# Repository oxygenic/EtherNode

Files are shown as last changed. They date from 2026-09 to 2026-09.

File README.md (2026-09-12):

# EtherNode
Slim STM32H7-based Ethernet device with several IOs and signal types which can be controlled via Telnet, supports MODBUS, REST and MQTT as well as small programs running from the device directly 

The EtherNode is an industrial IO-extender that comes with different types of input- and output-signals and a wide range of communication interfaces. Thus it can be used as remote Ethernet IO-module for different other scenarios and applications. Possible usage scenarios would be applications where the EtherNode acts as slim TCP module for a PLC and where it autonomously performs distributed and remote I/O operations that are triggered via simple and easy to use commands.

The EtherNode Compact IO module can be integrated into every machine network and provides the following features:
- wide-range power supply allows input voltages from 9V to 32V
- 8 galvanically insulated digital inputs which can be operated with external power in range 5..24V
- 2 of the digital inputs optionally can be used with a quadrature encoder for counting steps (position), speed and acceleration
- 8 galvanically insulated digital outputs which can be operated with external power in range 5..24V
- 2 of the digital outputs optionally can issue freely definable frequencies of up to 500 kHz with programmable pulse-width (PWM)
- 2 of the digital outputs optionally can be used to drive control two stepper motor axes with a step frequency of up to 100 kHz, acceleration ramps and referencing
- 2 high-impedance analogue inputs in range 0..10V with a resolution of 16 bits
- Ethernet interface to connect with host (control-PC / embedded device / PLC)
- control via Telnet ASCII commands, MODBUS, MQTT (plain and JSON) or HTTP REST API (plain and JSON)
- stand-alone operation: conditions and flows can be defined and stored on the device for autonomous operation wiht and without communication via the communication interfaces
- fully operational with any control device such as a PLC or even a plain PC or a Raspberry Pi
- board designed to fit into compact housing with DIN rail mounting clamp available at https://de.rs-online.com/web/p/din-schienen-gehause/1862290 and at https://de.rs-online.com/web/p/din-schienen-gehause/0336868

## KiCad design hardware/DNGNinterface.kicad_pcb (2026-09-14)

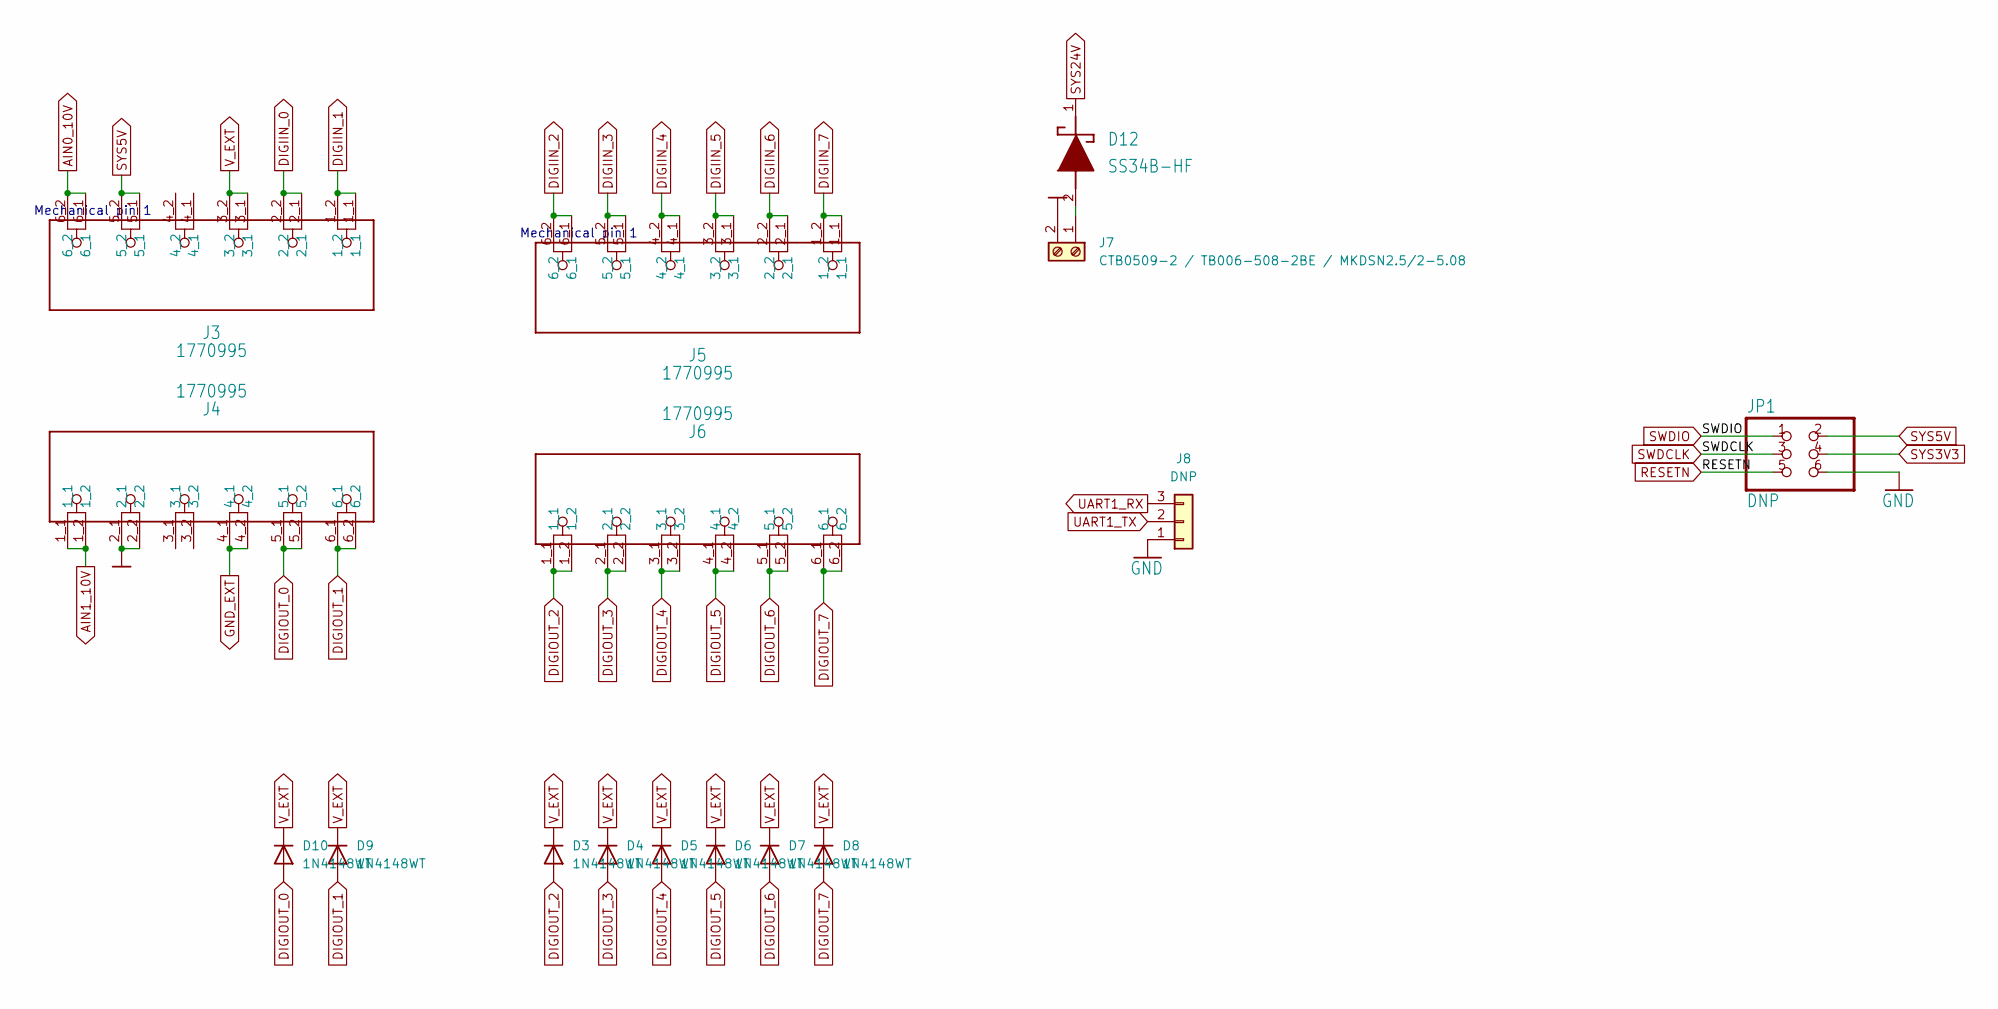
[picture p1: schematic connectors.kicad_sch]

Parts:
D3, D4, D5, D6, D7, D8, D9, D10: 1N4148WT; D_SOD-523
D12: SS34B-HF; SS34
J3, J4, J5, J6: 1770995; PHOENIX_1770995
J7: CTB0509-2 / TB006-508-2BE / MKDSN2.5/2-5.08; TerminalBlock_Phoenix_MKDS-1,5-2-5.08_1x02_P5.08mm_Horizont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
J8: DNP; PinHeader_1x03_P2.54mm_Vertical
JP1: DNP; PinHeader_2x03_P2.54mm_Vertical

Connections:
AIN0_10V: J3.6_1, J3.6_2; also elsewhere on the board
AIN1_10V: J4.1_1, J4.1_2; also elsewhere on the board
DIGIIN_0: J3.2_1, J3.2_2; also elsewhere on the board
DIGIIN_1: J3.1_1, J3.1_2; also elsewhere on the board
DIGIIN_2: J5.6_1, J5.6_2; also elsewhere on the board
DIGIIN_3: J5.5_1, J5.5_2; also elsewhere on the board
DIGIIN_4: J5.4_1, J5.4_2; also elsewhere on the board
DIGIIN_5: J5.3_1, J5.3_2; also elsewhere on the board
DIGIIN_6: J5.2_1, J5.2_2; also elsewhere on the board
DIGIIN_7: J5.1_1, J5.1_2; also elsewhere on the board
DIGIOUT_0: D10.2 (A), J4.5_1, J4.5_2; also elsewhere on the board
DIGIOUT_1: D9.2 (A), J4.6_1, J4.6_2; also elsewhere on the board
DIGIOUT_2: D3.2 (A), J6.1_1, J6.1_2; also elsewhere on the board
DIGIOUT_3: D4.2 (A), J6.2_1, J6.2_2; also elsewhere on the board
DIGIOUT_4: D5.2 (A), J6.3_1, J6.3_2; also elsewhere on the board
DIGIOUT_5: D6.2 (A), J6.4_1, J6.4_2; also elsewhere on the board
DIGIOUT_6: D7.2 (A), J6.5_1, J6.5_2; also elsewhere on the board
DIGIOUT_7: D8.2 (A), J6.6_1, J6.6_2; also elsewhere on the board
GND: J4.2_1, J4.2_2, J7.2, J8.1, JP1.6; also elsewhere on the board
GND_EXT: J4.4_1, J4.4_2; also elsewhere on the board
unnamed: D12.2 (A), J7.1
RESETN: JP1.5; also elsewhere on the board
SWDCLK: JP1.3; also elsewhere on the board
SWDIO: JP1.1; also elsewhere on the board
SYS3V3: JP1.4; also elsewhere on the board
SYS5V: J3.5_1, J3.5_2, JP1.2; also elsewhere on the board
SYS24V: D12.1 (K); also elsewhere on the board
UART1_RX: J8.3; also elsewhere on the board
UART1_TX: J8.2; also elsewhere on the board
V_EXT: D3.1 (K), D4.1 (K), D5.1 (K), D6.1 (K), D7.1 (K), D8.1 (K), D9.1 (K), D10.1 (K), J3.3_1, J3.3_2; also elsewhere on the board

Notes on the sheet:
Mechanical pin 1

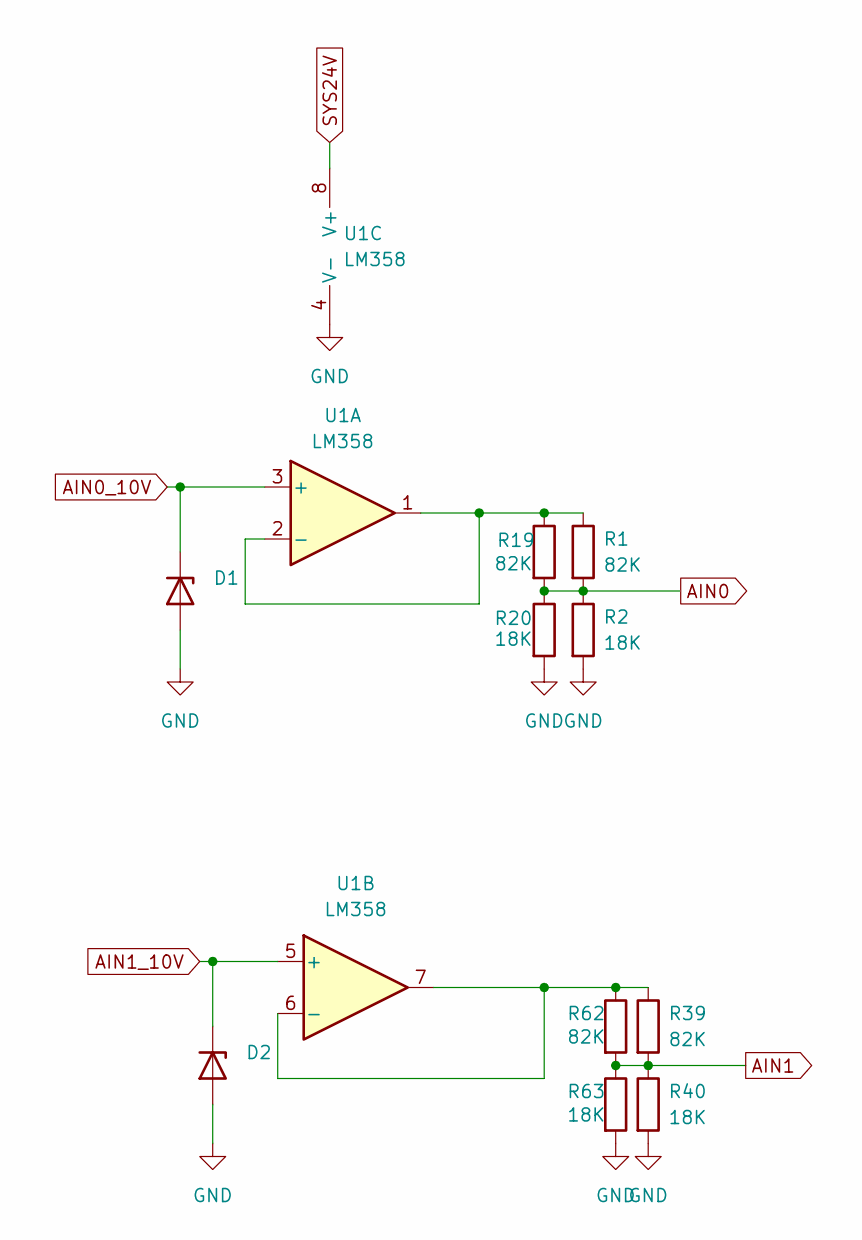
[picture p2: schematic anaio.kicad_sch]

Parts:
D1, D2: BZX84B10 / BZX84C10; SOT-23
R1, R19, R39, R62: 82K; R_0603_1608Metric
R2, R20, R40, R63: 18K; R_0603_1608Metric
U1: LM358; LM358DT

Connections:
AIN0: R1.2, R2.1, R19.2, R20.1; also elsewhere on the board
AIN0_10V: D1.3 (K), U1.3 (+); also elsewhere on the board
AIN1: R39.2, R40.1, R62.2, R63.1; also elsewhere on the board
AIN1_10V: D2.3 (K), U1.5 (+); also elsewhere on the board
GND: D1.1 (A), D2.1 (A), R2.2, R20.2, R40.2, R63.2, U1.4 (V-); also elsewhere on the board
unnamed: R1.1, R19.1, U1.1, U1.2 (-)
unnamed: R39.1, R62.1, U1.6 (-), U1.7
SYS24V: U1.8 (V+); also elsewhere on the board

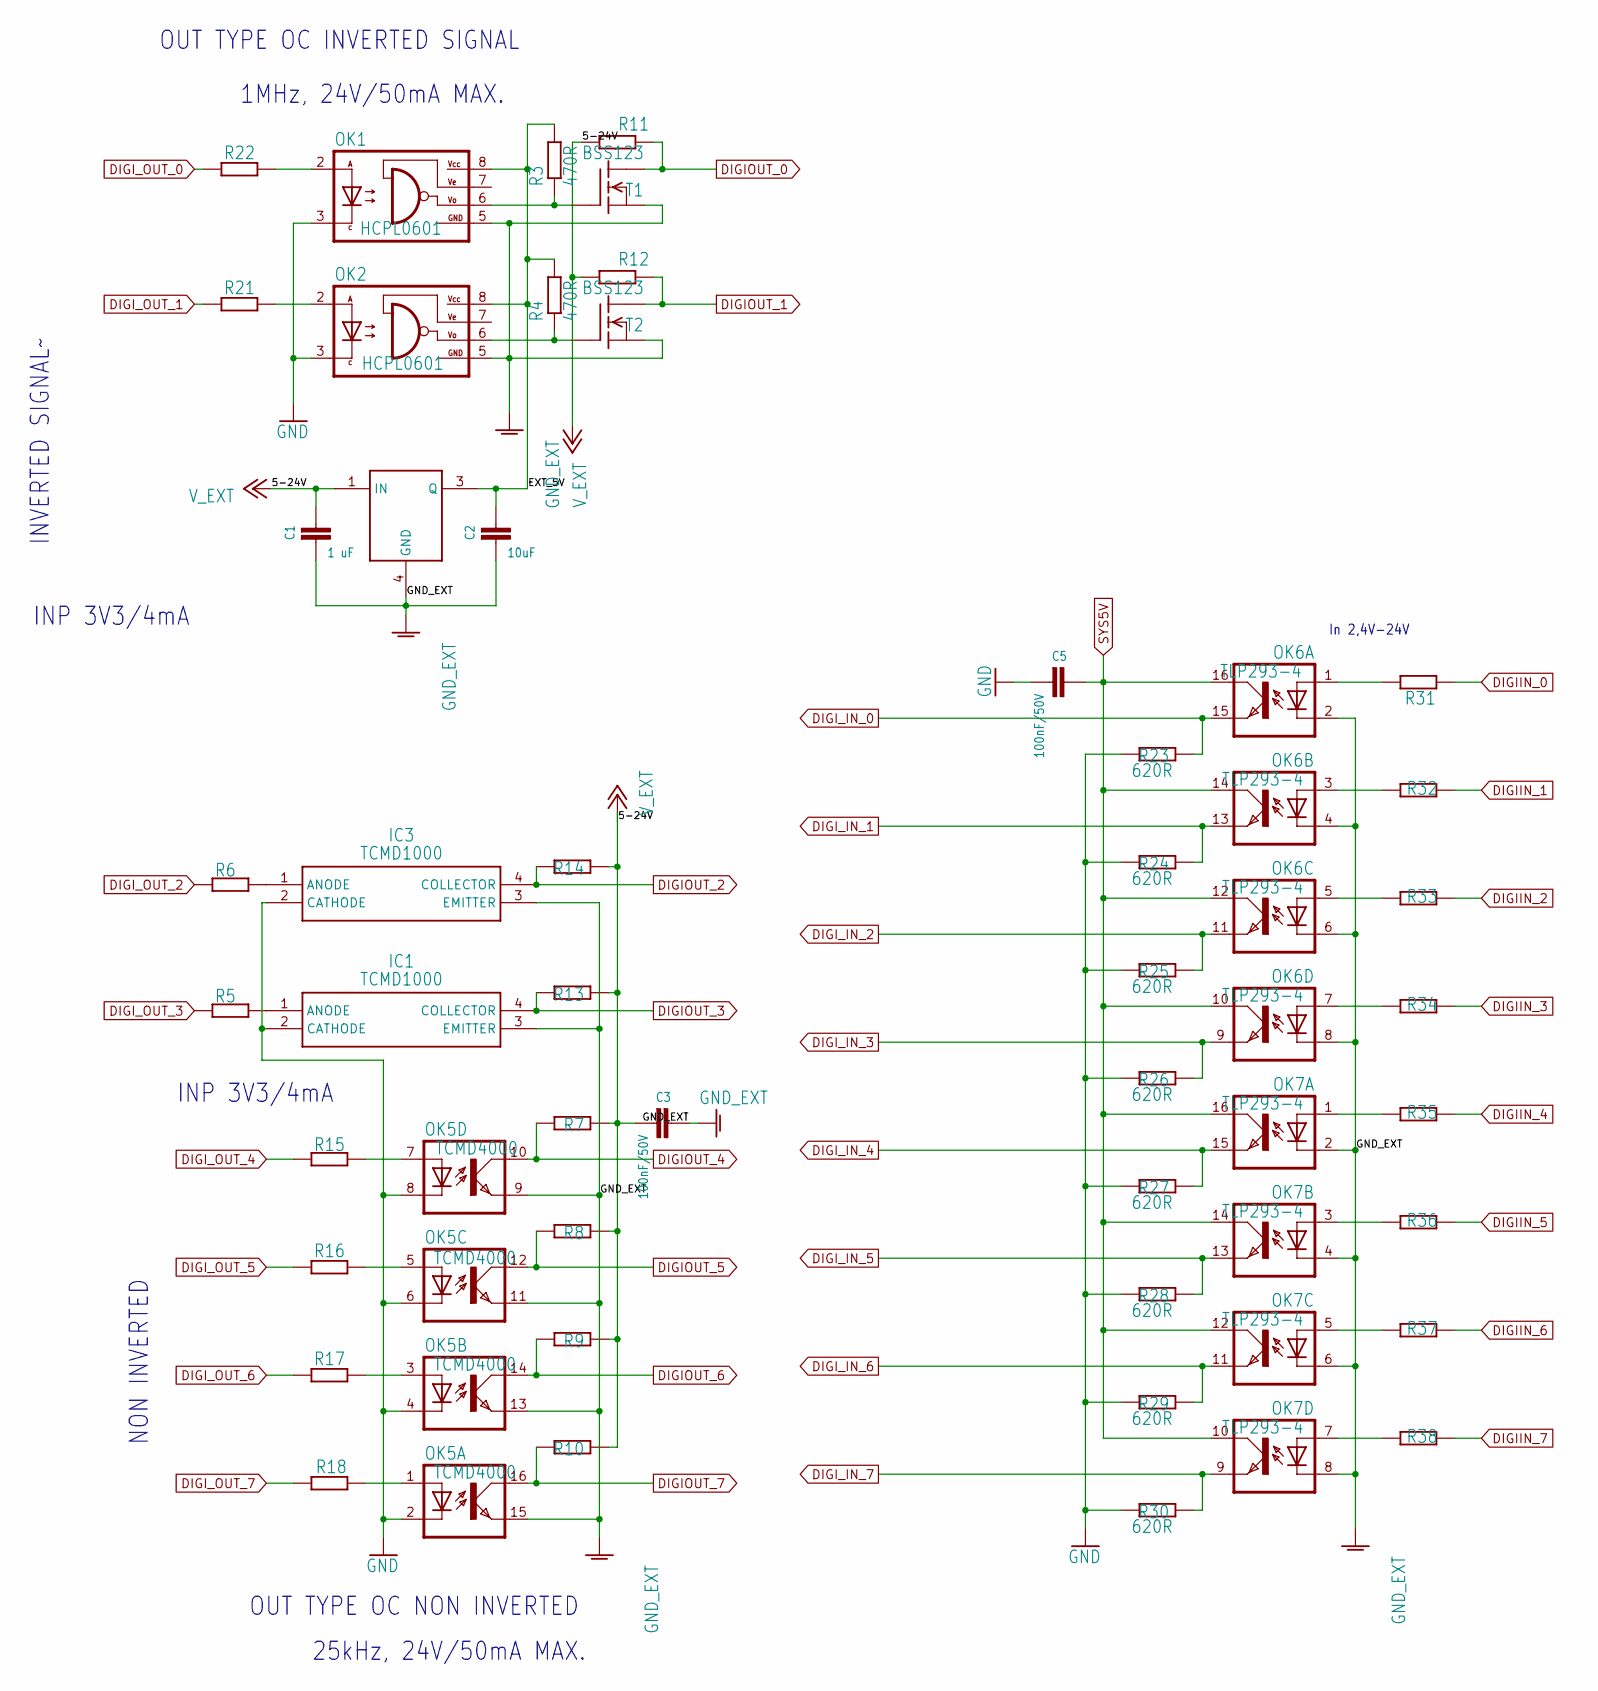
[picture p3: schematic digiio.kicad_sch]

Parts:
C1: 1 uF; C_0603_1608Metric
C2: 10uF; C_0603_1608Metric
C3, C5: 100nF/50V; C_0603_1608Metric
IC1, IC3: TCMD1000; SOIC127P695X210-4N
OK1, OK2: HCPL0601; HCLP0601
OK5: TCMD4000
OK6, OK7: TLP293-4; TLP293-4(E
R3, R4: 470R; R_0603_1608Metric
R5, R6, R15, R16, R17, R18, R21, R22: 270 R; R_0603_1608Metric
R7, R8, R9, R10, R11, R12, R13, R14: 2k2 0,75W ASC2010-2K2FT4 / RMCF2010JT2K20; R_2010_5025Metric
R23, R24, R25, R26, R27, R28, R29, R30: 620R; R_0603_1608Metric
R31, R32, R33, R34, R35, R36, R37, R38: 1k 0,75W RC2010JK-071KL / RMCF2010JT1K00 / CRMA20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; R_2010_5025Metric
T1, T2: BSS123
U$1: NCV4274CDT50RKG / NCV4274ADT50 / BD50FC0FP; NCV4274CDT50RKG

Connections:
/DigiIO/EXT_5V: C2.1, OK1.8 (VCC), OK2.8 (VCC), R3.2, R4.2, U$1.3 (Q)
DIGIIN_0: R31.2; also elsewhere on the board
DIGIIN_1: R32.2; also elsewhere on the board
DIGIIN_2: R33.2; also elsewhere on the board
DIGIIN_3: R34.2; also elsewhere on the board
DIGIIN_4: R35.2; also elsewhere on the board
DIGIIN_5: R36.2; also elsewhere on the board
DIGIIN_6: R37.2; also elsewhere on the board
DIGIIN_7: R38.2; also elsewhere on the board
DIGIOUT_0: R11.2, T1.3 (D1); also elsewhere on the board
DIGIOUT_1: R12.2, T2.3 (D1); also elsewhere on the board
DIGIOUT_2: IC3.4 (COLLECTOR), R14.2; also elsewhere on the board
DIGIOUT_3: IC1.4 (COLLECTOR), R13.2; also elsewhere on the board
DIGIOUT_4: OK5.10 (COL), R7.2; also elsewhere on the board
DIGIOUT_5: OK5.12 (COL), R8.2; also elsewhere on the board
DIGIOUT_6: OK5.14 (COL), R9.2; also elsewhere on the board
DIGIOUT_7: OK5.16 (COL), R10.2; also elsewhere on the board
DIGI_IN_0: OK6.15 (EMIT), R23.1; also elsewhere on the board
DIGI_IN_1: OK6.13 (EMIT), R24.1; also elsewhere on the board
DIGI_IN_2: OK6.11 (EMIT), R25.1; also elsewhere on the board
DIGI_IN_3: OK6.9 (EMIT), R26.1; also elsewhere on the board
DIGI_IN_4: OK7.15 (EMIT), R27.1; also elsewhere on the board
DIGI_IN_5: OK7.13 (EMIT), R28.1; also elsewhere on the board
DIGI_IN_6: OK7.11 (EMIT), R29.1; also elsewhere on the board
DIGI_IN_7: OK7.9 (EMIT), R30.1; also elsewhere on the board
DIGI_OUT_0: R22.1; also elsewhere on the board
DIGI_OUT_1: R21.1; also elsewhere on the board
DIGI_OUT_2: R6.1; also elsewhere on the board
DIGI_OUT_3: R5.1; also elsewhere on the board
DIGI_OUT_4: R15.1; also elsewhere on the board
DIGI_OUT_5: R16.1; also elsewhere on the board
DIGI_OUT_6: R17.1; also elsewhere on the board
DIGI_OUT_7: R18.1; also elsewhere on the board
GND: C5.2, IC1.2 (CATHODE), IC3.2 (CATHODE), OK1.3 (C), OK2.3 (C), OK5.2 (C), OK5.4 (C), OK5.6 (C), OK5.8 (C), R23.2, R24.2, R25.2, R26.2, R27.2, R28.2, R29.2, R30.2; also elsewhere on the board
GND_EXT: C1.2, C2.2, C3.1, IC1.3 (EMITTER), IC3.3 (EMITTER), OK1.5 (GND), OK2.5 (GND), OK5.9 (EMIT), OK5.11 (EMIT), OK5.13 (EMIT), OK5.15 (EMIT), OK6.2 (C), OK6.4 (C), OK6.6 (C), OK6.8 (C), OK7.2 (C), OK7.4 (C), OK7.6 (C), OK7.8 (C), T1.2 (S), T2.2 (S), U$1.4 (GND); also elsewhere on the board
unnamed: IC1.1 (ANODE), R5.2
unnamed: IC3.1 (ANODE), R6.2
unnamed: OK1.2 (A), R22.2
unnamed: OK1.6 (VO), R3.1, T1.1 (G)
unnamed: OK2.2 (A), R21.2
unnamed: OK2.6 (VO), R4.1, T2.1 (G)
unnamed: OK5.1 (A), R18.2
unnamed: OK5.3 (A), R17.2
unnamed: OK5.5 (A), R16.2
unnamed: OK5.7 (A), R15.2
unnamed: OK6.1 (A), R31.1
unnamed: OK6.3 (A), R32.1
unnamed: OK6.5 (A), R33.1
unnamed: OK6.7 (A), R34.1
unnamed: OK7.1 (A), R35.1
unnamed: OK7.3 (A), R36.1
unnamed: OK7.5 (A), R37.1
unnamed: OK7.7 (A), R38.1
SYS5V: C5.1, OK6.10 (COL), OK6.12 (COL), OK6.14 (COL), OK6.16 (COL), OK7.10 (COL), OK7.12 (COL), OK7.14 (COL), OK7.16 (COL); also elsewhere on the board
V_EXT: C1.1, C3.2, R7.1, R8.1, R9.1, R10.1, R11.1, R12.1, R13.1, R14.1, U$1.1 (IN); also elsewhere on the board

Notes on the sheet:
OUT TYPE OC NON INVERTED
NON INVERTED
INP 3V3/4mA
OUT TYPE OC INVERTED SIGNAL
25kHz, 24V/50mA MAX.
In 2,4V-24V
1MHz, 24V/50mA MAX.
INVERTED SIGNAL~~{}

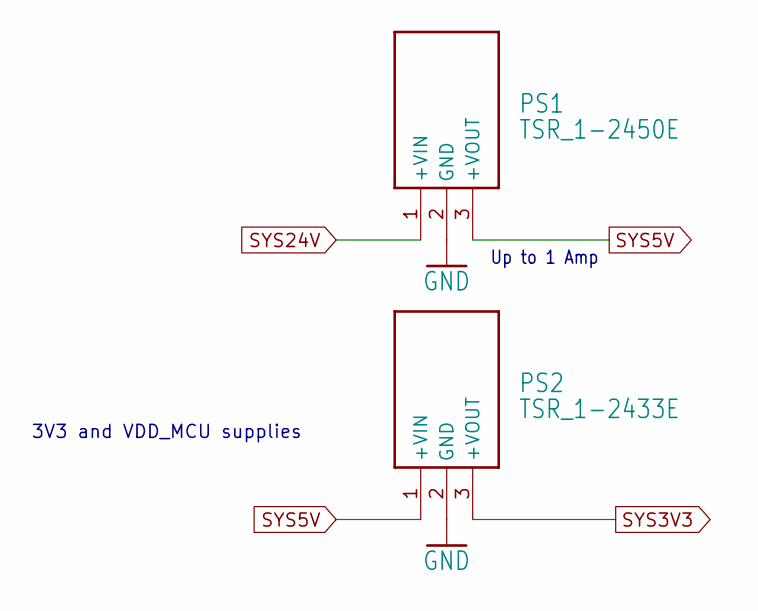
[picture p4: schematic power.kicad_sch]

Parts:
PS1: TSR_1-2450E; Converter_DCDC_TRACO_TSR1-xxxxE_THT
PS2: TSR_1-2433E; Converter_DCDC_TRACO_TSR1-xxxxE_THT

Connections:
GND: PS1.2 (GND), PS2.2 (GND); also elsewhere on the board
SYS3V3: PS2.3 (+VOUT); also elsewhere on the board
SYS5V: PS1.3 (+VOUT), PS2.1 (+VIN); also elsewhere on the board
SYS24V: PS1.1 (+VIN); also elsewhere on the board

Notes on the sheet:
Up to 1 Amp
3V3 and VDD_MCU supplies

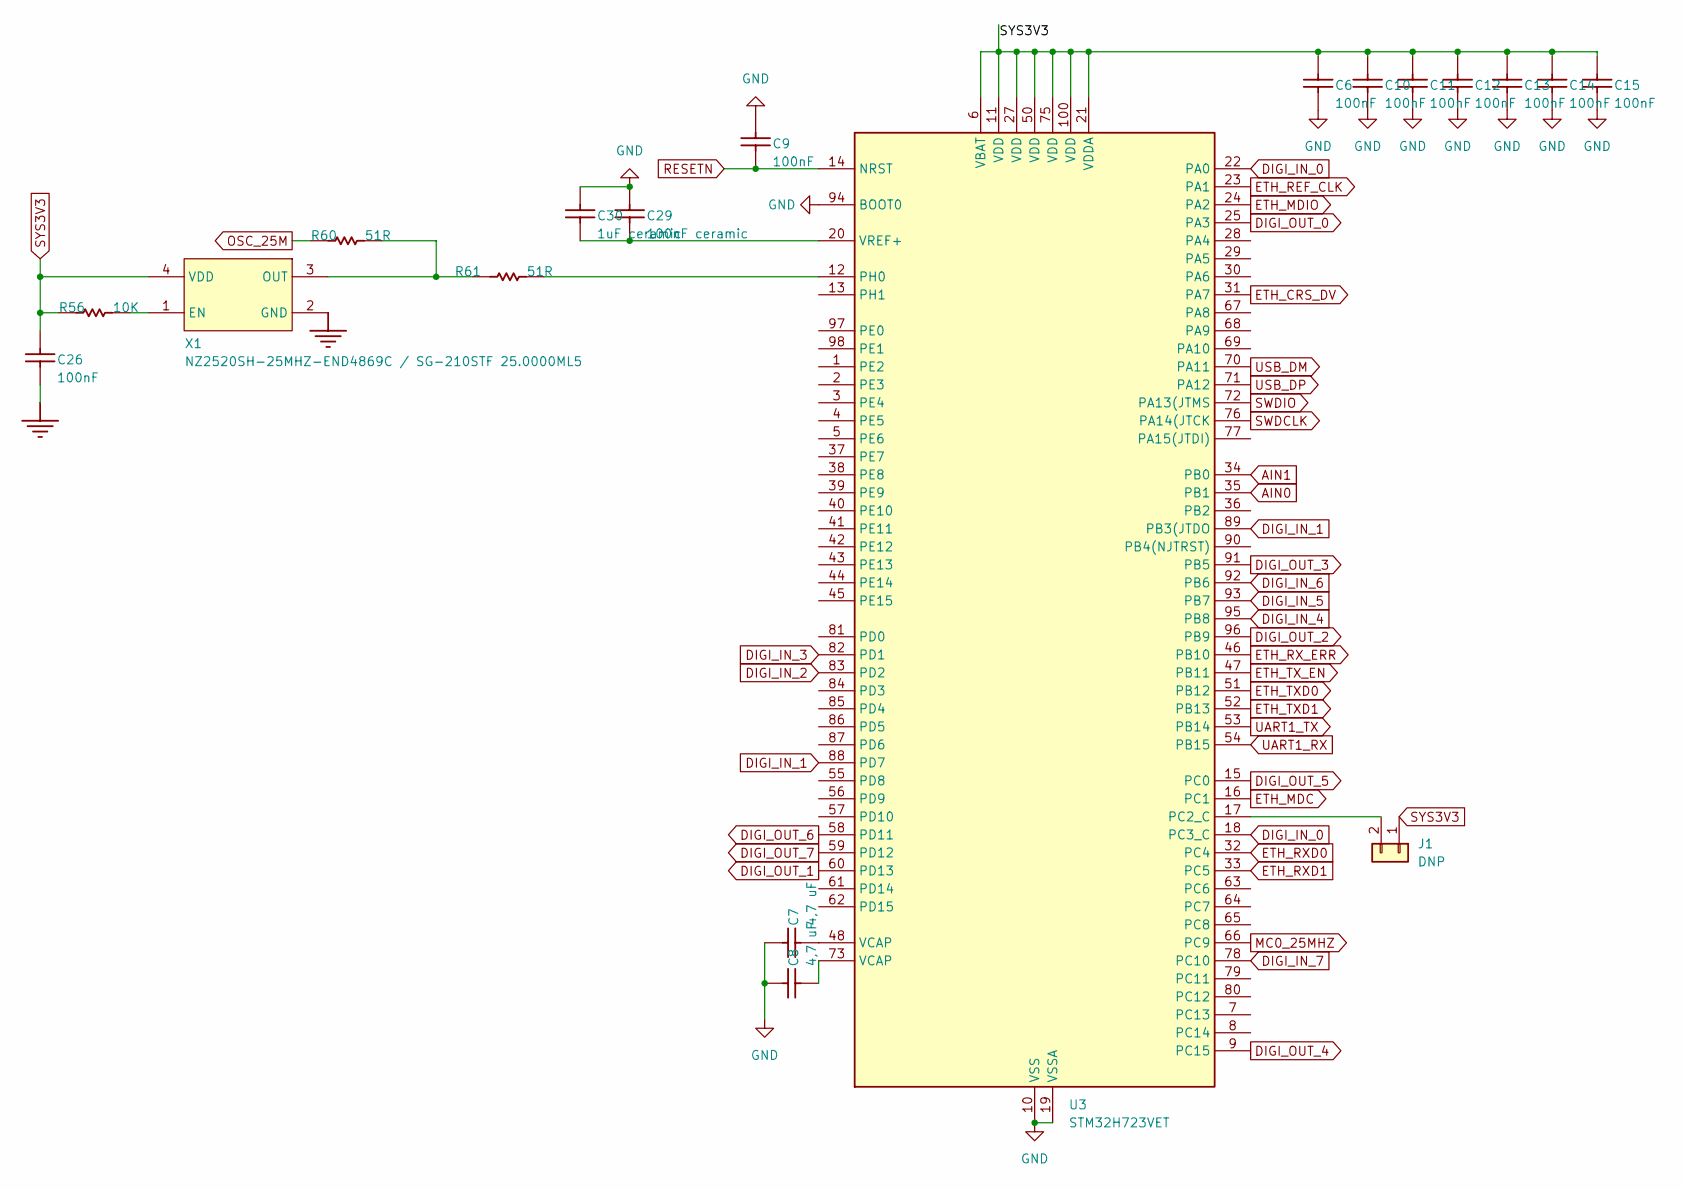
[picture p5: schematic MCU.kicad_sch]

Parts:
C6, C9, C10, C11, C12, C13, C14, C15, C26: 100nF; C_0603_1608Metric; PART_TYPE Capacitor
C7, C8: 4,7 uF; C_0603_1608Metric; PART_TYPE Capacitor
C29: 100nF ceramic; C_0603_1608Metric; PART_TYPE Capacitor
C30: 1uF ceramic; C_0603_1608Metric; PART_TYPE Capacitor
J1: DNP; PinHeader_1x02_P1.00mm_Vertical
R56: 10K; R_0603_1608Metric; PART_TYPE Resistor
R60, R61: 51R; R_0603_1608Metric; PART_TYPE Resistor
U3: STM32H723VET; LQFP-100_14x14mm_P0.5mm
X1: NZ2520SH-25MHZ-END4869C / SG-210STF 25.0000ML5; SG210STF250000ML5; PART_TYPE Crystal_Osc

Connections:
AIN0: U3.35 (PB1); also elsewhere on the board
AIN1: U3.34 (PB0); also elsewhere on the board
DIGI_IN_0: U3.18 (PC3_C), U3.22 (PA0); also elsewhere on the board
DIGI_IN_1: U3.88 (PD7), U3.89 (PB3(JTDO); also elsewhere on the board
DIGI_IN_2: U3.83 (PD2); also elsewhere on the board
DIGI_IN_3: U3.82 (PD1); also elsewhere on the board
DIGI_IN_4: U3.95 (PB8); also elsewhere on the board
DIGI_IN_5: U3.93 (PB7); also elsewhere on the board
DIGI_IN_6: U3.92 (PB6); also elsewhere on the board
DIGI_IN_7: U3.78 (PC10); also elsewhere on the board
DIGI_OUT_0: U3.25 (PA3); also elsewhere on the board
DIGI_OUT_1: U3.60 (PD13); also elsewhere on the board
DIGI_OUT_2: U3.96 (PB9); also elsewhere on the board
DIGI_OUT_3: U3.91 (PB5); also elsewhere on the board
DIGI_OUT_4: U3.9 (PC15); also elsewhere on the board
DIGI_OUT_5: U3.15 (PC0); also elsewhere on the board
DIGI_OUT_6: U3.58 (PD11); also elsewhere on the board
DIGI_OUT_7: U3.59 (PD12); also elsewhere on the board
ETH_CRS_DV: U3.31 (PA7); also elsewhere on the board
ETH_MDC: U3.16 (PC1); also elsewhere on the board
ETH_MDIO: U3.24 (PA2); also elsewhere on the board
ETH_REF_CLK: U3.23 (PA1); also elsewhere on the board
ETH_RXD0: U3.32 (PC4); also elsewhere on the board
ETH_RXD1: U3.33 (PC5); also elsewhere on the board
ETH_RX_ERR: U3.46 (PB10); also elsewhere on the board
ETH_TXD0: U3.51 (PB12); also elsewhere on the board
ETH_TXD1: U3.52 (PB13); also elsewhere on the board
ETH_TX_EN: U3.47 (PB11); also elsewhere on the board
GND: C6.1, C7.2, C8.2, C9.2, C10.1, C11.1, C12.1, C13.1, C14.1, C15.1, C26.1, C29.2, C30.2, U3.10 (VSS), U3.19 (VSSA), U3.26 (VSS), U3.49 (VSS), U3.74 (VSS), U3.94 (BOOT0), U3.99 (VSS), X1.2 (GND); also elsewhere on the board
MC0_25MHZ: U3.66 (PC9)
unnamed: C7.1, U3.48 (VCAP)
unnamed: C8.1, U3.73 (VCAP)
unnamed: J1.2, U3.17 (PC2_C)
unnamed: R61.2, U3.12 (PH0)
unnamed: C29.1, C30.1, U3.20 (VREF+)
unnamed: R56.1, X1.1 (EN)
unnamed: R60.2, R61.1, X1.3 (OUT)
OSC_25M: R60.1; also elsewhere on the board
RESETN: C9.1, U3.14 (NRST); also elsewhere on the board
SWDCLK: U3.76 (PA14(JTCK); also elsewhere on the board
SWDIO: U3.72 (PA13(JTMS); also elsewhere on the board
SYS3V3: C6.2, C10.2, C11.2, C12.2, C13.2, C14.2, C15.2, C26.2, J1.1, R56.2, U3.6 (VBAT), U3.11 (VDD), U3.21 (VDDA), U3.27 (VDD), U3.50 (VDD), U3.75 (VDD), U3.100 (VDD), X1.4 (VDD); also elsewhere on the board
UART1_RX: U3.54 (PB15); also elsewhere on the board
UART1_TX: U3.53 (PB14); also elsewhere on the board
USB_DM: U3.70 (PA11)
USB_DP: U3.71 (PA12)

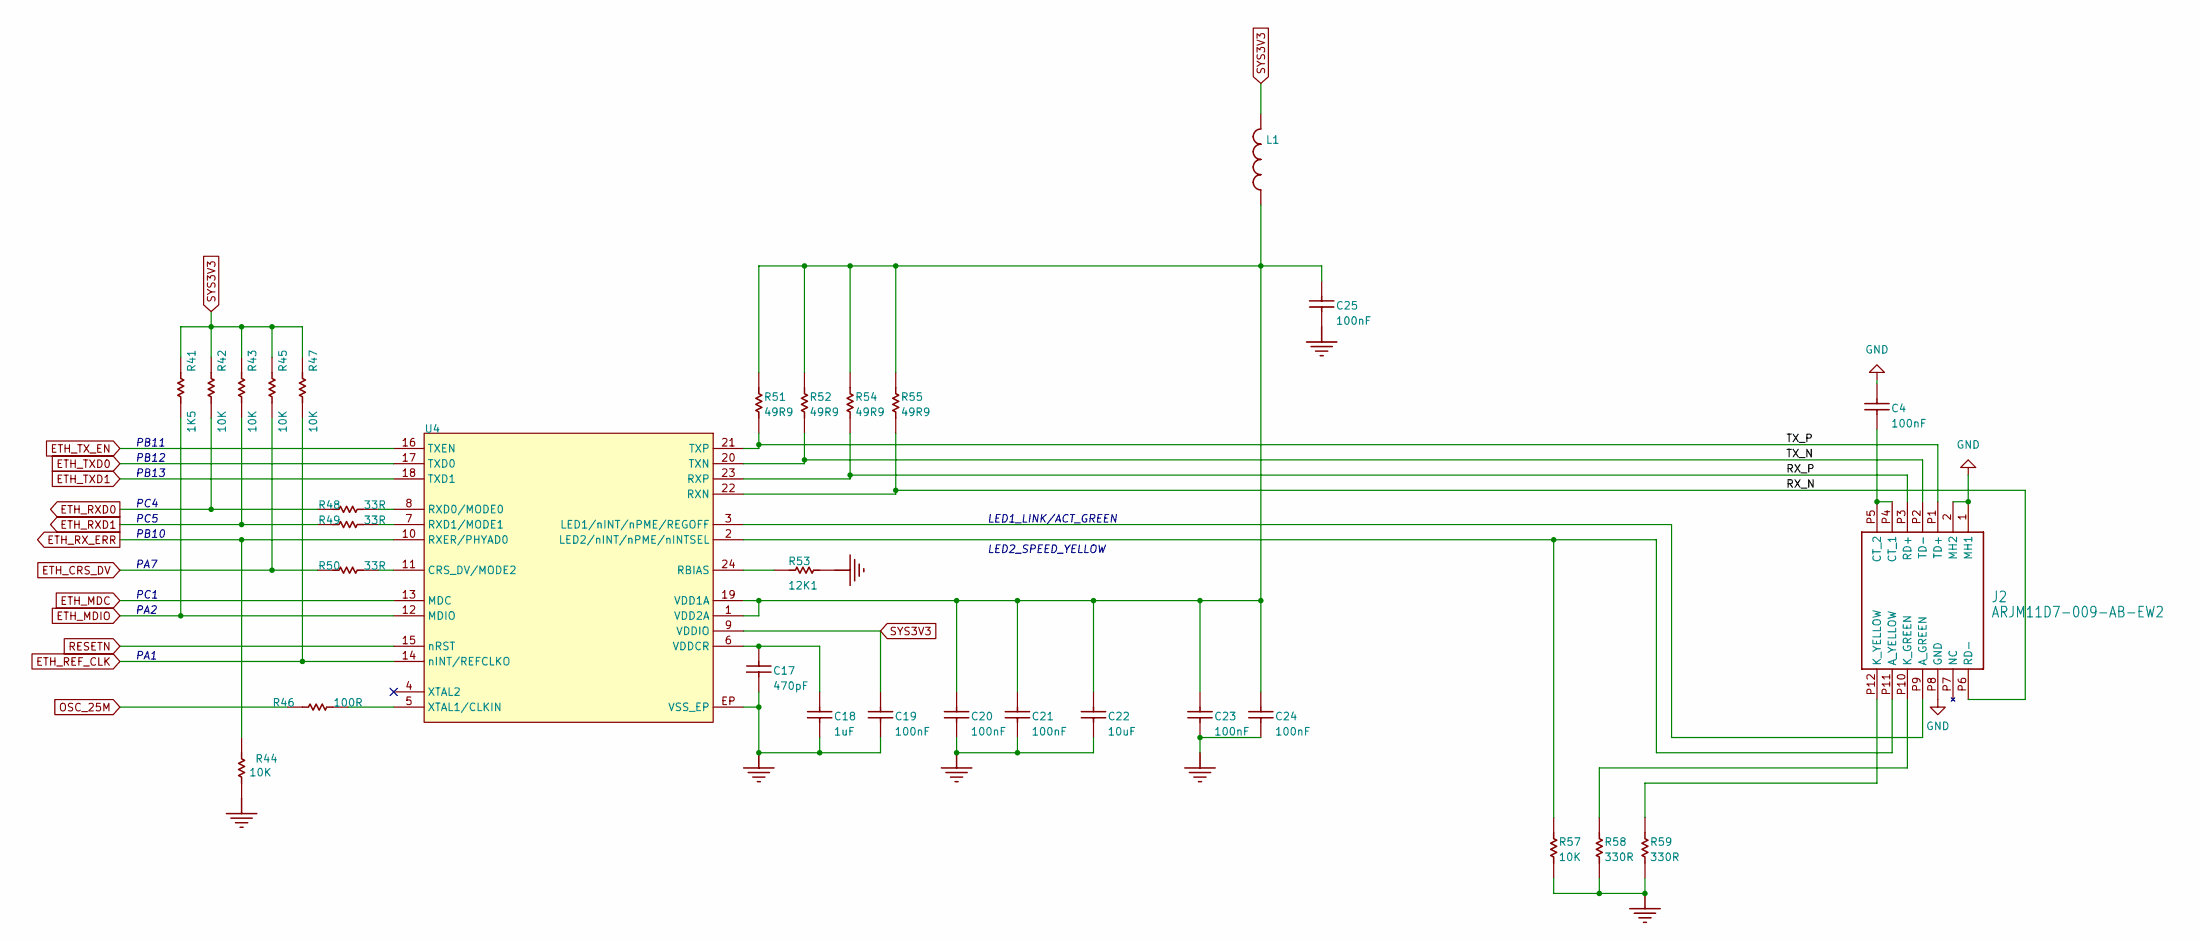
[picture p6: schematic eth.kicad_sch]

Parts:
C4: 100nF; C_0603_1608Metric; PART_TYPE Capacitor
C17: 470pF; C_0402_1005Metric; PART_TYPE Capacitor
C18: 1uF; C_0402_1005Metric; PART_TYPE Capacitor
C19, C20, C21, C23, C24, C25: 100nF; C_0402_1005Metric; PART_TYPE Capacitor
C22: 10uF; C_0402_1005Metric; PART_TYPE Capacitor
J2: ARJM11D7-009-AB-EW2; ARJM11D7009ABEW2
L1: FCM1608KF-601T03; L_0603_1608Metric; PART_TYPE Inductor
R41: 1K5; R_0402_1005Metric; PART_TYPE Resistor
R42, R43, R44, R45, R47, R57: 10K; R_0402_1005Metric; PART_TYPE Resistor
R46: 100R; R_0402_1005Metric; PART_TYPE Resistor
R48, R49, R50: 33R; R_0402_1005Metric; PART_TYPE Resistor
R51, R52, R54, R55: 49R9; R_0603_1608Metric; PART_TYPE Resistor
R53: 12K1; R_0402_1005Metric; PART_TYPE Resistor
R58, R59: 330R; R_0402_1005Metric; PART_TYPE Resistor
U4: LAN8742A-CZ-TR; LAN8742A; PART_TYPE IC

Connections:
/ETH/RX_N: J2.P6 (RD-), R55.1, U4.22 (RXN)
/ETH/RX_P: J2.P3 (RD+), R54.1, U4.23 (RXP)
/ETH/TX_N: J2.P2 (TD-), R52.1, U4.20 (TXN)
/ETH/TX_P: J2.P1 (TD+), R51.1, U4.21 (TXP)
ETH_CRS_DV: R45.2, R50.1; also elsewhere on the board
ETH_MDC: U4.13 (MDC); also elsewhere on the board
ETH_MDIO: R41.1, U4.12 (MDIO); also elsewhere on the board
ETH_REF_CLK: R47.2, U4.14 (nINT/REFCLKO); also elsewhere on the board
ETH_RXD0: R42.1, R48.1; also elsewhere on the board
ETH_RXD1: R43.1, R49.1; also elsewhere on the board
ETH_RX_ERR: R44.1, U4.10 (RXER/PHYAD0); also elsewhere on the board
ETH_TXD0: U4.17 (TXD0); also elsewhere on the board
ETH_TXD1: U4.18 (TXD1); also elsewhere on the board
ETH_TX_EN: U4.16 (TXEN); also elsewhere on the board
GND: C4.1, C17.1, C18.1, C19.2, C20.2, C21.2, C22.1, C23.2, C24.2, C25.1, J2.1 (MH1), J2.2 (MH2), J2.P8 (GND), R44.2, R53.2, R57.1, R58.1, R59.1, U4.EP (VSS_EP); also elsewhere on the board
unnamed: J2.P9 (A_GREEN), U4.3 (LED1/nINT/nPME/REGOFF)
unnamed: J2.P11 (A_YELLOW), R57.2, U4.2 (LED2/nINT/nPME/nINTSEL)
unnamed: C4.2, J2.P4 (CT_1), J2.P5 (CT_2)
unnamed: J2.P10 (K_GREEN), R58.2
unnamed: J2.P12 (K_YELLOW), R59.2
unnamed: R50.2, U4.11 (CRS_DV/MODE2)
unnamed: R53.1, U4.24 (RBIAS)
unnamed: R48.2, U4.8 (RXD0/MODE0)
unnamed: R49.2, U4.7 (RXD1/MODE1)
unnamed: C20.1, C21.1, C22.2, C23.1, C24.1, C25.2, L1.1, R51.2, R52.2, R54.2, R55.2, U4.1 (VDD2A), U4.19 (VDD1A)
unnamed: C17.2, C18.2, U4.6 (VDDCR)
unnamed: R46.2, U4.5 (XTAL1/CLKIN)
OSC_25M: R46.1; also elsewhere on the board
RESETN: U4.15 (nRST); also elsewhere on the board
SYS3V3: C19.1, L1.2, R41.2, R42.2, R43.2, R45.1, R47.1, U4.9 (VDDIO); also elsewhere on the board

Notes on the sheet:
PB13
LED2_SPEED_YELLOW
PC5
PC1
PB10
PA2
PA7
PB11
LED1_LINK/ACT_GREEN
PC4
PB12
PA1

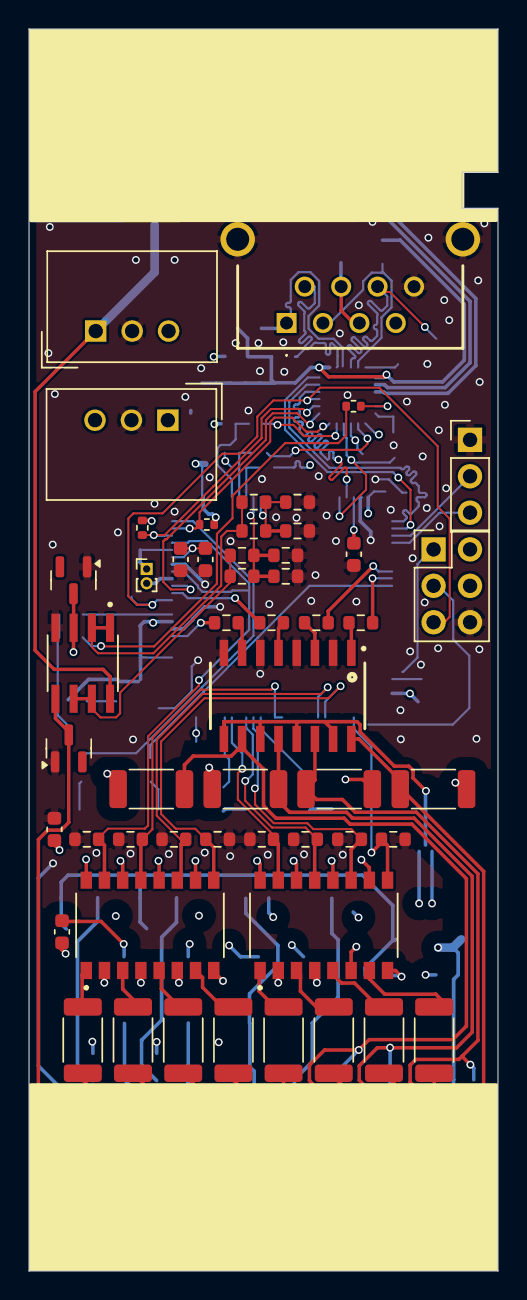
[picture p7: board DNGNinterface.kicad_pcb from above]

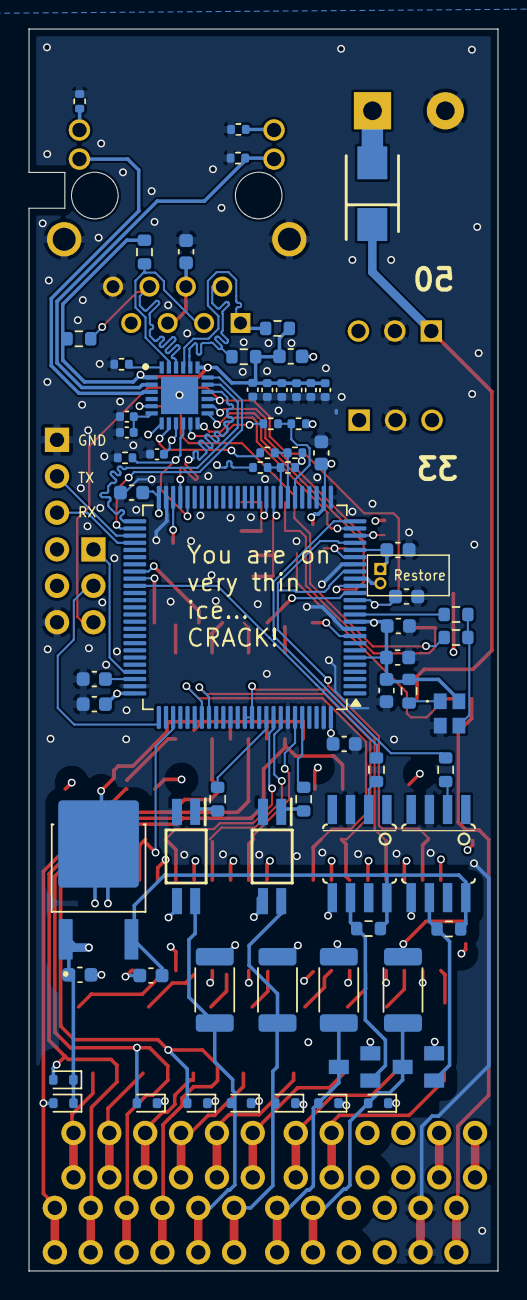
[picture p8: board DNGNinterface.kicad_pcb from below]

Board: 4 copper layers, 32.7 x 86.6 mm, 127 parts (70 on the bottom side), 103 nets.

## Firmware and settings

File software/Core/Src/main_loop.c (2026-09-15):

#include <string.h>
#include <stdint.h>

#include "main.h"
#include "main_loop.h"
#include "lwip.h"
#include "network_mqtt.h"
#include "debug.h"
#include "network.h"
#include "hardware.h"
#include "stepper.h"
#if defined(ENABLE_MQTT) || defined(ENABLE_MODBUS)
#include "F:\wxWidgets-3\demos\OpenAPC\libsmartfactory\libsmartfactory.h"
#endif
#include "oapc_libio.h"

#define STATIC_IP_ADDRESS_RW_ACCESS     (0x00000000)

#define STATIC_IP_ADDRESS_MQTT          (0xC0A802FC)

#define IP4_ADDR_INIT(x)   ((ip4_addr_t){ .addr = (x) })

struct global_config globalConfig={CONFIG_STRUCT_ID,
                                   0x00,1,0xFF,
                                   IP4_ADDR_INIT(STATIC_IP_ADDRESS_PORT1),IP4_ADDR_INIT(STATIC_GW_ADDRESS_PORT1),IP4_ADDR_INIT(STATIC_NM_ADDRESS_PORT1),IP4_ADDR_INIT(STATIC_IP_ADDRESS_RW_ACCESS),
                                   450,450,(uint16_t)(ANA_CALIB_FACTOR+1800),(uint16_t)(ANA_CALIB_FACTOR+1800),
                                   CONFIG_FLAG_DISABLE_MQTT|CONFIG_FLAG_DISABLE_MQTT_JSON, // flags
                                   0,0,0,0,
                                   IP4_ADDR_INIT(STATIC_IP_ADDRESS_MQTT),1025,"","","HALnode",
                                   "",
                                   IP4_ADDR_INIT(0),0,0, // SNTP IP, time offset and next update time
                                   0,0,0,0,0,0,
                                   {
                                   {evtUnused,cmpNone,evtUnused,0,trgUnused,opNone,evtUnused,0,trgUnused,opNone,evtUnused,0},
                                   {evtUnused,cmpNone,evtUnused,0,trgUnused,opNone,evtUnused,0,trgUnused,opNone,evtUnused,0},
                                   {evtUnused,cmpNone,evtUnused,0,trgUnused,opNone,evtUnused,0,trgUnused,opNone,evtUnused,0},
                                   {evtUnused,cmpNone,evtUnused,0,trgUnused,opNone,evtUnused,0,trgUnused,opNone,evtUnused,0},
                                   {evtUnused,cmpNone,evtUnused,0,trgUnused,opNone,evtUnused,0,trgUnused,opNone,evtUnused,0},
                                   {evtUnused,cmpNone,evtUnused,0,trgUnused,opNone,evtUnused,0,trgUnused,opNone,evtUnused,0},
                                   {evtUnused,cmpNone,evtUnused,0,trgUnused,opNone,evtUnused,0,trgUnused,opNone,evtUnused,0},
                                   {evtUnused,cmpNone,evtUnused,0,trgUnused,opNone,evtUnused,0,trgUnused,opNone,evtUnused,0},
                                   {evtUnused,cmpNone,evtUnused,0,trgUnused,opNone,evtUnused,0,trgUnused,opNone,evtUnused,0},
                                   {evtUnused,cmpNone,evtUnused,0,trgUnused,opNone,evtUnused,0,trgUnused,opNone,evtUnused,0},
                                   {evtUnused,cmpNone,evtUnused,0,trgUnused,opNone,evtUnused,0,trgUnused,opNone,evtUnused,0},
                                   {evtUnused,cmpNone,evtUnused,0,trgUnused,opNone,evtUnused,0,trgUnused,opNone,evtUnused,0},
                                   {evtUnused,cmpNone,evtUnused,0,trgUnused,opNone,evtUnused,0,trgUnused,opNone,evtUnused,0},
                                   {evtUnused,cmpNone,evtUnused,0,trgUnused,opNone,evtUnused,0,trgUnused,opNone,evtUnused,0},
                                   {evtUnused,cmpNone,evtUnused,0,trgUnused,opNone,evtUnused,0,trgUnused,opNone,evtUnused,0},
                                   {evtUnused,cmpNone,evtUnused,0,trgUnused,opNone,evtUnused,0,trgUnused,opNone,evtUnused,0},
                                   {evtUnused,cmpNone,evtUnused,0,trgUnused,opNone,evtUnused,0,trgUnused,opNone,evtUnused,0},
                                   {evtUnused,cmpNone,evtUnused,0,trgUnused,opNone,evtUnused,0,trgUnused,opNone,evtUnused,0},
                                   {evtUnused,cmpNone,evtUnused,0,trgUnused,opNone,evtUnused,0,trgUnused,opNone,evtUnused,0},
                                   {evtUnused,cmpNone,evtUnused,0,trgUnused,opNone,evtUnused,0,trgUnused,opNone,evtUnused,0},
                                   {evtUnused,cmpNone,evtUnused,0,trgUnused,opNone,evtUnused,0,trgUnused,opNone,evtUnused,0},
                                   {evtUnused,cmpNone,evtUnused,0,trgUnused,opNone,evtUnused,0,trgUnused,opNone,evtUnused,0},
                                   {evtUnused,cmpNone,evtUnused,0,trgUnused,opNone,evtUnused,0,trgUnused,opNone,evtUnused,0},
                                   {evtUnused,cmpNone,evtUnused,0,trgUnused,opNone,evtUnused,0,trgUnused,opNone,evtUnused,0},
                                   {evtUnused,cmpNone,evtUnused,0,trgUnused,opNone,evtUnused,0,trgUnused,opNone,evtUnused,0},
                                   {evtUnused,cmpNone,evtUnused,0,trgUnused,opNone,evtUnused,0,trgUnused,opNone,evtUnused,0},
                                   {evtUnused,cmpNone,evtUnused,0,trgUnused,opNone,evtUnused,0,trgUnused,opNone,evtUnused,0},
                                   {evtUnused,cmpNone,evtUnused,0,trgUnused,opNone,evtUnused,0,trgUnused,opNone,evtUnused,0},
                                   {evtUnused,cmpNone,evtUnused,0,trgUnused,opNone,evtUnused,0,trgUnused,opNone,evtUnused,0},
                                   {evtUnused,cmpNone,evtUnused,0,trgUnused,opNone,evtUnused,0,trgUnused,opNone,evtUnused,0},
                                   {evtUnused,cmpNone,evtUnused,0,trgUnused,opNone,evtUnused,0,trgUnused,opNone,evtUnused,0},
                                   {evtUnused,cmpNone,evtUnused,0,trgUnused,opNone,evtUnused,0,trgUnused,opNone,evtUnused,0},
                                   },
                                   250, //msec
                                   MAX_EVT_NUM,0, // steps, reserved
                                   {50000.0F,50000.0F,1000.0F,1000.0F,1000.0F,1000.0F,1000.0F},
#ifdef DEBUG
                                   {15000.0F,15000.0F,500.0F,500.0F,500.0F,500.0F,500.0F},
#else
                                   {100000.0F,100000.0F,1100.0F,1100.0F,1100.0F,1100.0F,1100.0F},
#endif
                                   };
struct global_state  globalState={0,0,
   #ifdef ENABLE_MODBUS
                                  NULL,
   #endif
                                  "",
                                  0,0
};
       uint8_t           testMode=0,evtListCtr=MAX_EVT_NUM,cfgListCtr=255;
static int32_t           lastMotfSpeed;
       uint32_t          lastMotfValue=0;
static volatile uint64_t g_time_ms=0;
       uint64_t          lastDInChange=0,lastAIn0Change=0,lastAIn1Change=0;


#ifdef ENABLE_MQTT
static void mqttPublishEncoder(const char *node)
{
   if (lib_mqtt_start(globalConfig.mqttIP,globalConfig.mqttPort,globalState.mqttMachineID,globalConfig.mqttUser,globalConfig.mqttPwd))
   {
      char tmpStr[300+1];
      char tmpVal[70+1];

      snprintf(tmpStr,300,"%s/%s/%s",globalConfig.mqttTopic,globalState.mqttMachineID,node);
      snprintf(tmpVal,70,"{ \"pos\": %u, \"spd\": %d, \"acc\": %d, \"time_ms\": %lu }",(unsigned int)lastMotfValue,(int)globalState.motfSpeed,(int)globalState.motfAccel,(long unsigned int)globalState.encChange);
      lib_mqtt_publish(tmpStr,tmpVal);
   }
}


static void mqttPublishAxis(const char *node)
{
   const uint64_t ts=time_ms_get();
   if (lib_mqtt_start(globalConfig.mqttIP,globalConfig.mqttPort,globalState.mqttMachineID,globalConfig.mqttUser,globalConfig.mqttPwd))
   {
      char tmpStr[300+1];
      char tmpVal[100+1];

      snprintf(tmpStr,300,"%s/%s/%s",globalConfig.mqttTopic,globalState.mqttMachineID,node);
      snprintf(tmpVal,100,"{ \"axis\": %u,  \"pos\": %d, \"spd\": %u, \"time_ms\": %lu }",(unsigned int)stepper.currAxis,(int)stepper.current_pos[stepper.currAxis],(unsigned int)stepper.v,(long unsigned int)ts);
      lib_mqtt_publish(tmpStr,tmpVal);
   }
}


static void mqttPublish(const char *node,const int32_t value,const uint8_t isHex,const int64_t timestamp)
{
   if ((globalConfig.flags & CONFIG_FLAG_DISABLE_MQTT_JSON)==0)
   {
      if (lib_mqtt_start(globalConfig.mqttIP,globalConfig.mqttPort,globalState.mqttMachineID,globalConfig.mqttUser,globalConfig.mqttPwd))
      {
         char tmpStr[300+1];
         char tmpVal[70+1];

         snprintf(tmpStr,300,"%s/%s/%s",globalConfig.mqttTopic,globalState.mqttMachineID,node);
         snprintf(tmpVal,70,"{ \"val\": %u, \"time_ms\": %lu }",(unsigned int)value,(long unsigned int)timestamp);
         lib_mqtt_publish(tmpStr,tmpVal);
      }
   }
   else if ((globalConfig.flags & CONFIG_FLAG_DISABLE_MQTT)==0)
   {
      if (lib_mqtt_start(globalConfig.mqttIP,globalConfig.mqttPort,globalState.mqttMachineID,globalConfig.mqttUser,globalConfig.mqttPwd))
      {
         char tmpStr[300+1];
         char tmpVal[20+1];

         snprintf(tmpStr,300,"%s/%s/%s",globalConfig.mqttTopic,globalState.mqttMachineID,node);
         if (isHex) snprintf(tmpVal,20,"0x%X",(int)value);
         else snprintf(tmpVal,20,"%d",(int)value);
         lib_mqtt_publish(tmpStr,tmpVal);
      }
   }
}
#endif


void HAL_TIM_PeriodElapsedCallback(TIM_HandleTypeDef *htim)
{
   if (htim->Instance==TIM6)
   {
      stepper_timer_isr();
   }
   else if (htim->Instance==TIM5)
   {
      int32_t i;

      g_time_ms++;
      for (i=0; i<MAX_TIM_NUM; i++)
       globalState.timer[i]++;
      //HAL_GPIO_TogglePin(DIGI_OUT_7_GPIO_Port,DIGI_OUT_7_Pin);
   }
   else if(htim->Instance==TIM3)
   {
      const uint32_t current=__HAL_TIM_GET_COUNTER(&htim2);
      lastMotfSpeed=globalState.motfSpeed;
      globalState.motfSpeed=(current-lastMotfValue)*60;
      globalState.motfAccel=abs(globalState.motfSpeed)-abs(lastMotfSpeed);
      lastMotfValue=current;
      //HAL_GPIO_TogglePin(DIGI_OUT_6_GPIO_Port,DIGI_OUT_6_Pin);
   }
}

const uint64_t time_ms_get(void)
{
   __disable_irq();      // Interrupt kurz sperren
   const uint64_t t = g_time_ms;
   __enable_irq();       // Interrupt wieder freigeben
   return t;
}


char *handleListConfig(const int32_t cfgNum)
{
   switch (cfgNum)
   {
      case 0:
         snprintf(r,DATA_LENGTH,"ciout 0x%X\r\n",globalConfig.digiInit);
         return r;
      case 1:
         snprintf(r,DATA_LENGTH,"cimsk 0x%X\r\n",globalConfig.digiMask);
         return r;
      case 10:
      {
         const ip_addr_t tip={ntohl(globalConfig.ip.addr)};

         snprintf(r,DATA_LENGTH,"csip0 %s\r\n",ip4addr_ntoa(&tip));
         return r;
      }
      case 11:
      {
         const ip_addr_t tip={ntohl(globalConfig.gw.addr)};

         snprintf(r,DATA_LENGTH,"csgw0 %s\r\n",ip4addr_ntoa(&tip));
         return r;
      }
      case 12:
      {
         const ip_addr_t tip={ntohl(globalConfig.nm.addr)};

         snprintf(r,DATA_LENGTH,"csnm0 %s\r\n",ip4addr_ntoa(&tip));
         return r;
      }
      case 13:
      {
         const ip_addr_t tip={ntohl(globalConfig.rwip.addr)};

         snprintf(r,DATA_LENGTH,"csipw %s\r\n",ip4addr_ntoa(&tip));
         return r;
      }
      case 14:
      {
         const ip_addr_t tip={ntohl(globalConfig.mqttIP.addr)};

         snprintf(r,DATA_LENGTH,"csipq %s\r\n",ip4addr_ntoa(&tip));
         return r;
      }
      case 15:
         snprintf(r,DATA_LENGTH,"csptq %d\r\n",globalConfig.mqttPort);
         return r;
      case 16:
         if (isWriteAllowed) snprintf(r,DATA_LENGTH,"csusq %s\r\n",globalConfig.mqttUser);
         else strncpy(r,"csusq ********\r\n",DATA_LENGTH);
         return r;
      case 17:
         if (isWriteAllowed) snprintf(r,DATA_LENGTH,"cspwq %s\r\n",globalConfig.mqttPwd);
         else strncpy(r,"cspwq ********\r\n",DATA_LENGTH);
         return r;
      case 18:
         snprintf(r,DATA_LENGTH,"cstpq %s\r\n",globalConfig.mqttTopic);
         return r;
      case 19:
         strncpy(r,"cdflg 2147483648\r\n",DATA_LENGTH);
         return r;
      case 20:
         snprintf(r,DATA_LENGTH,"csflg %u\r\n",(unsigned int)globalConfig.flags);
         return r;
      case 30:
      case 31:
      case 32:
      case 33:
      case 34:
      case 35:
      case 36:
         snprintf(r,DATA_LENGTH,"caxsv %d %d\r\n",(int)(cfgNum-12),(int)globalConfig.stepVmax[cfgNum-30]);
         return r;
      case 40:
      case 41:
      case 42:
      case 43:
      case 44:
      case 45:
      case 46:
         snprintf(r,DATA_LENGTH,"caxsa %d %d\r\n",(int)(cfgNum-19),(int)globalConfig.stepA[cfgNum-40]);
         return r;
      case 50:
         snprintf(r,DATA_LENGTH,"csets %d\r\n",globalConfig.evtInterval);
         return r;
      case 51:
         snprintf(r,DATA_LENGTH,"csepn %d\r\n",globalConfig.evtProcNum);
         return r;

      case 200:
         snprintf(r,DATA_LENGTH,"csa0f %d\r\n",globalConfig.ana0fac);
         return r;
      case 201:
         snprintf(r,DATA_LENGTH,"csa1f %d\r\n",globalConfig.ana1fac);
         return r;
      case 202:
         snprintf(r,DATA_LENGTH,"csa0o %u\r\n",(unsigned int)globalConfig.ana0offs);
         return r;
      case 203:
         snprintf(r,DATA_LENGTH,"csa1o %u\r\n",(unsigned int)globalConfig.ana1offs);
         return r;
      case 254:
         evtListCtr=0;
         break;
   }
   return NULL;
}


void main_loop(void)
{
   uint32_t DInnew=0;
   int32_t  ain0new=0,ain1new=0;
   char     recvBuffer[UART_RECV_BUFFER+1],*sendBuffer=NULL;
   uint32_t uartReceived=0,sendBufferSize=0,sendBufferPos=0;
   uint32_t ain0sum=0,ain1sum=0;
   uint16_t ain0cnt=0,ain1cnt=0;
   uint32_t currMotfValue=0;
   uint64_t lastEvtTime=0;

//   HAL_NVIC_SetPriority(SysTick_IRQn, 15, 0);
   HAL_InitTick(TICK_INT_PRIORITY);

   uint32_t lastTick=HAL_GetTick();
   uint32_t lastSendTick=HAL_GetTick();
   handleEvents(0); // initial call with all timers set to 0, here initialisations can be done with comparison of TimX == 0
   HAL_TIM_Base_Start_IT(&htim5);
   HAL_TIM_Base_Start_IT(&htim3);
   HAL_TIM_Encoder_Start(&htim2,TIM_CHANNEL_ALL);
   for (;;)
   {
//HAL_GPIO_TogglePin(DIGI_OUT_5_GPIO_Port,DIGI_OUT_5_Pin);
      stepper_homing_state();
      MX_LWIP_Process();
      DInnew=(hw_gpio_get() & globalConfig.digiMask);

      const int32_t sendTickDiff=HAL_GetTick()-lastSendTick;

      {
         const uint64_t currTime=time_ms_get();
         bool  eventTriggered=false;

         if (DInnew!=globalState.digiINState)
          lastDInChange=currTime;

         if ((globalConfig.flags & CONFIG_FLAG_EVENT_ON_DIN_MASK)!=0)
         {
            const int32_t evtBit=((globalConfig.flags & CONFIG_FLAG_EVENT_ON_DIN_MASK)>>CONFIG_FLAG_EVENT_ON_DIN_SHIFT);

            if (((globalState.digiINState & evtBit)==0) &&
                ((DInnew & evtBit)!=0)) eventTriggered=true;
         }

         if (eventTriggered)
         {
            handleEvents(DInnew);
         }
         else if ((globalConfig.evtInterval>0) &&
             (currTime>=lastEvtTime+globalConfig.evtInterval))
         {
            lastEvtTime=currTime;
            handleEvents(DInnew);
         }
         else if (cfgListCtr<255)
         {
            char *r=handleListConfig(cfgListCtr);
            if (r) telnet_append_response(r);
            cfgListCtr++;
         }
         else if (evtListCtr<MAX_EVT_NUM)
         {
            char *r=handleListEvent(evtListCtr);
            if (r) telnet_append_response(r);
            evtListCtr++;
            if (evtListCtr>=MAX_EVT_NUM) telnet_append_response(TELNET_PROMPT);
         }
      }

      if ((globalConfig.flags & CONFIG_FLAG_ENABLE_QENCP)==CONFIG_FLAG_ENABLE_QENCP)
      {
         static uint_fast8_t quencStep=0;

         quencStep++;
         switch (quencStep)
         {
            case 1:
               globalState.digiOut|=0x04;
               break;
            case 20:
               globalState.digiOut|=0x08;
               break;
            case 30:
               globalState.digiOut&=~0x04;
               break;
            case 40:
               globalState.digiOut&=~0x08;
               break;
            case 50:
               quencStep=0;
               break;
         }
         hw_gpio_set(globalState.digiOut);
      }

      // currMotfValue is "current" only in context of comparison, the very latest MOTF-value according to the
      // encoder register is stored in lastMotfValue
      if (currMotfValue!=lastMotfValue)
      {
         globalState.encChange=time_ms_get();
         currMotfValue=lastMotfValue;
         globalState.motfValue=currMotfValue;
#ifdef ENABLE_MQTT
         if ((globalConfig.flags & CONFIG_FLAG_NO_ENC_AT_MQTT)==0)
         {
            if ((globalConfig.flags & CONFIG_FLAG_DISABLE_MQTT_JSON)==0)
            {
               mqttPublishEncoder("Enc");
            }
            else
            {
               mqttPublish("EncPos",currMotfValue,0,0);
               mqttPublish("EncSpd",globalState.motfSpeed,0,0);
               mqttPublish("EncAcc",globalState.motfAccel,0,0);
            }
         }
#endif
      }
      if (stepper.last_current_pos[stepper.currAxis]!=stepper.current_pos[stepper.currAxis])
      {
         static uint32_t waitCtr=0;

         waitCtr++;
         if (waitCtr>150)
         {
            waitCtr=0;
            if ((globalConfig.flags & CONFIG_FLAG_DISABLE_MQTT_JSON)==0)
            {
               mqttPublishAxis("Axis");
            }
            else
            {
               if (stepper.currAxis==0)
               {
                  mqttPublish("Axis0Pos",stepper.current_pos[stepper.currAxis],0,0);
                  mqttPublish("Axis0Spd",stepper.v,0,0);
               }
               else if (stepper.currAxis==1)
               {
                  mqttPublish("Axis1Pos",stepper.current_pos[stepper.currAxis],0,0);
                  mqttPublish("Axis1Spd",stepper.v,0,0);
               }
            }
            stepper.last_current_pos[stepper.currAxis]=stepper.current_pos[stepper.currAxis];
         }
      }

      if ((DInnew!=globalState.digiINState) || (sendTickDiff>20000))
      {
         lastSendTick=HAL_GetTick();
         globalState.digiINState=DInnew;
#ifdef ENABLE_MQTT
         if ((globalConfig.flags & CONFIG_FLAG_NO_DIN_AT_MQTT)==0)
         {
            mqttPublish("DIn",DInnew,1,lastDInChange);
         }
#endif
#ifdef ENABLE_TELNET
         if ((globalConfig.flags & CONFIG_FLAG_TELNET_PUSH_DIGI)==CONFIG_FLAG_TELNET_PUSH_DIGI)
         {
            char cmd[20+1];

            snprintf(cmd,20,"cginp 0x%X\r\n",(int)DInnew);
            telnet_append_response(cmd);
         }
#endif
      }


      // TODO: take analogue calibration values into account
      ain0new=hw_get_analogue(0);
      if (ain0new>=0)
      {
         ain0cnt++;
         ain0sum+=ain0new;
      }
      // TODO: take analogue calibration values into account
      ain1new=hw_get_analogue(1);
      if (ain1new>=0)
      {
         ain1cnt++;
         ain1sum+=ain1new;
      }

      const int32_t tickDiff=HAL_GetTick()-lastTick;
      if ((tickDiff>500) || (ain0cnt>10000) || (ain1cnt>10000) || (sendTickDiff>20000))
      {
         lastTick=HAL_GetTick();
         if (ain0cnt>0)
         {
            ain0new=ain0sum/ain0cnt;
            if (ain0new!=globalState.ain0state)
             lastAIn0Change=time_ms_get();
            if ((ain0new>=0) && (ain0cnt>100) && (abs(ain0new-globalState.ain0state)>8))
            {
               globalState.ain0state=ain0new;
               ain0cnt=0;
               ain0sum=0;
#ifdef ENABLE_MQTT
               mqttPublish("AIn0",ain0new,0,lastAIn0Change);
#endif
#ifdef ENABLE_TELNET
               if ((globalConfig.flags & CONFIG_FLAG_TELNET_PUSH_ANA)==CONFIG_FLAG_TELNET_PUSH_ANA)
               {
                  char cmd[20+1];

                  snprintf(cmd,20,"cgana0 %d\r\n",(int)ain0new);
                  telnet_append_response(cmd);
               }
#endif
            }
         }
         if (ain1cnt>0)
         {
            ain1new=ain1sum/ain1cnt;
            if (ain1new!=globalState.ain1state)
             lastAIn1Change=time_ms_get();
            if ((ain1new>=0) && (ain1cnt>100) && (abs(ain1new-globalState.ain1state)>8))
            {
               globalState.ain1state=ain1new;
               ain1cnt=0;
               ain1sum=0;
#ifdef ENABLE_MQTT
               mqttPublish("AIn1",ain1new,0,lastAIn0Change);
#endif
#ifdef ENABLE_TELNET
               if ((globalConfig.flags & CONFIG_FLAG_TELNET_PUSH_ANA)==CONFIG_FLAG_TELNET_PUSH_ANA)
               {
                  char cmd[20+1];

                  snprintf(cmd,20,"cgana1 %d\r\n",(int)ain1new);
                  telnet_append_response(cmd);
               }
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

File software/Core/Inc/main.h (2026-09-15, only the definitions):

#define DIGI_OUT_4_Pin GPIO_PIN_15
#define DIGI_OUT_4_GPIO_Port GPIOC
#define DIGI_OUT_5_Pin GPIO_PIN_0
#define DIGI_OUT_5_GPIO_Port GPIOC
#define SET_DEFAULT_Pin GPIO_PIN_2
#define SET_DEFAULT_GPIO_Port GPIOC
#define DIGI_IN_0_Pin GPIO_PIN_3
#define DIGI_IN_0_GPIO_Port GPIOC
#define DIGI_OUT_0_Pin GPIO_PIN_3
#define DIGI_OUT_0_GPIO_Port GPIOA
#define AIN1_Pin GPIO_PIN_0
#define AIN1_GPIO_Port GPIOB
#define AIN0_Pin GPIO_PIN_1
#define AIN0_GPIO_Port GPIOB
#define DIGI_OUT_6_Pin GPIO_PIN_11
#define DIGI_OUT_6_GPIO_Port GPIOD
#define DIGI_OUT_7_Pin GPIO_PIN_12
#define DIGI_OUT_7_GPIO_Port GPIOD
#define DIGI_OUT_1_Pin GPIO_PIN_13
#define DIGI_OUT_1_GPIO_Port GPIOD
#define DIGI_IN_7_Pin GPIO_PIN_10
#define DIGI_IN_7_GPIO_Port GPIOC
#define DIGI_IN_3_Pin GPIO_PIN_1
#define DIGI_IN_3_GPIO_Port GPIOD
#define DIGI_IN_2_Pin GPIO_PIN_2
#define DIGI_IN_2_GPIO_Port GPIOD
#define DIGI_IN_1OLD_Pin GPIO_PIN_3
#define DIGI_IN_1OLD_GPIO_Port GPIOD
#define DIGI_IN_0OLD_Pin GPIO_PIN_4
#define DIGI_IN_0OLD_GPIO_Port GPIOD
#define DIGI_IN_1_Pin GPIO_PIN_7
#define DIGI_IN_1_GPIO_Port GPIOD
#define DIGI_OUT_3_Pin GPIO_PIN_5
#define DIGI_OUT_3_GPIO_Port GPIOB
#define DIGI_IN_6_Pin GPIO_PIN_6
#define DIGI_IN_6_GPIO_Port GPIOB
#define DIGI_IN_5_Pin GPIO_PIN_7
#define DIGI_IN_5_GPIO_Port GPIOB
#define DIGI_IN_4_Pin GPIO_PIN_8
#define DIGI_IN_4_GPIO_Port GPIOB
#define DIGI_OUT_2_Pin GPIO_PIN_9
#define DIGI_OUT_2_GPIO_Port GPIOB

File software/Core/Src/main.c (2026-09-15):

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
/* Includes ------------------------------------------------------------------*/
#include "main.h"
#include "lwip.h"

/* USER CODE BEGIN Includes */
#include <string.h>

#include "main_loop.h"
#include "network.h"
#include "debug.h"
#include "flash_storage.h"
#include "main_loop.h"
#include "hardware.h"
#if defined(ENABLE_MQTT) || defined(ENABLE_MODBUS)
#include "F:\wxWidgets-3\demos\OpenAPC\libsmartfactory\libsmartfactory.h"
#endif
#include "oapc_libio.h"
#include "assert.h"
#include "network_mqtt.h"
#include "httpd.h"
#include "stepper.h"
/* USER CODE END Includes */

ADC_HandleTypeDef hadc1;
ADC_HandleTypeDef hadc2;

LPTIM_HandleTypeDef hlptim1;
LPTIM_HandleTypeDef hlptim5;

TIM_HandleTypeDef htim2;
TIM_HandleTypeDef htim3;
TIM_HandleTypeDef htim5;
TIM_HandleTypeDef htim6;

UART_HandleTypeDef huart1;

void SystemClock_Config(void);
void PeriphCommonClock_Config(void);
static void MPU_Config(void);
static void MX_GPIO_Init(void);
static void MX_ADC1_Init(void);
static void MX_ADC2_Init(void);
static void MX_LPTIM1_Init(void);
static void MX_LPTIM5_Init(void);
static void MX_USART1_UART_Init(void);
static void MX_TIM2_Init(void);
static void MX_TIM3_Init(void);
static void MX_TIM5_Init(void);
static void MX_TIM6_Init(void);
/* USER CODE BEGIN 0 */
static uint8_t modbus_pwm_set_cb(const uint16_t num,const uint32_t freq,const uint32_t pulse,const void *data)
{
   switch (num)
   {
      case 100:
         if (hw_pwm_set(0,freq,pulse)==HAL_OK) return 1;
         break;
      case 104:
         if (hw_pwm_set(1,freq,pulse)==HAL_OK) return 1;
         break;
   }
   return 0;
}

static uint8_t modbus_digi_set_cb(const uint16_t num,const uint8_t val,const void *data)
{
   switch (num)
   {
      case 0:
         if (val) globalState.digiOut|=0x01;
         else globalState.digiOut&=~0x01;
         break;
      case 1:
         if (val) globalState.digiOut|=0x02;
         else globalState.digiOut&=~0x02;
         break;
      case 2:
         if (val) globalState.digiOut|=0x04;
         else globalState.digiOut&=~0x04;
         break;
      case 3:
         if (val) globalState.digiOut|=0x08;
         else globalState.digiOut&=~0x08;
         break;
      case 4:
         if (val) globalState.digiOut|=0x10;
         else globalState.digiOut&=~0x10;
         break;
      case 5:
         if (val) globalState.digiOut|=0x20;
         else globalState.digiOut&=~0x20;
         break;
      case 6:
         if (val) globalState.digiOut|=0x40;
         else globalState.digiOut&=~0x40;
         break;
      case 7:
         if (val) globalState.digiOut|=0x80;
         else globalState.digiOut&=~0x80;
         break;
      default:
         return 0;
   }
   hw_gpio_set(globalState.digiOut);
   return 1;
}


static uint8_t modbus_digi_get_cb(const uint16_t num,uint8_t *val,const void *data)
{
   switch (num)
   {
      case 0:
         if ((globalState.digiOut & 0x01)==0x01) *val=1;
         else *val=0;
         break;
      case 1:
         if ((globalState.digiOut & 0x02)==0x02) *val=1;
         else *val=0;
         break;
      case 2:
         if ((globalState.digiOut & 0x04)==0x04) *val=1;
         else *val=0;
         break;
      case 3:
         if ((globalState.digiOut & 0x08)==0x08) *val=1;
         else *val=0;
         break;
      case 4:
         if ((globalState.digiOut & 0x10)==0x10) *val=1;
         else *val=0;
         break;
      case 5:
         if ((globalState.digiOut & 0x20)==0x20) *val=1;
         else *val=0;
         break;
      case 6:
         if ((globalState.digiOut & 0x40)==0x40) *val=1;
         else *val=0;
         break;
      case 7:
         if ((globalState.digiOut & 0x80)==0x80) *val=1;
         else *val=0;
         break;

      case 10000:
         if ((globalState.digiINState & 0x01)==0x01) *val=1;
         else *val=0;
         break;
      case 10001:
         if ((globalState.digiINState & 0x02)==0x02) *val=1;
         else *val=0;
         break;
      case 10002:
         if ((globalState.digiINState & 0x04)==0x04) *val=1;
         else *val=0;
         break;
      case 10003:
         if ((globalState.digiINState & 0x08)==0x08) *val=1;
         else *val=0;
         break;
      case 10004:
         if ((globalState.digiINState & 0x10)==0x10) *val=1;
         else *val=0;
         break;
      case 10005:
         if ((globalState.digiINState & 0x20)==0x20) *val=1;
         else *val=0;
         break;
      case 10006:
         if ((globalState.digiINState & 0x40)==0x40) *val=1;
         else *val=0;
         break;
      case 10007:
         if ((globalState.digiINState & 0x80)==0x80) *val=1;
         else *val=0;
         break;
      default:
         return 0;
   }
   return 1;
}


static uint8_t modbus_ana_get_cb(const uint16_t num,uint16_t *val,const void *data)
{
   switch (num)
   {
      case 0:
         *val=globalState.ain0state;
         break;
      case 1:
         *val=globalState.ain1state;
         break;
      default:
         return 0;
   }
   return 1;
}

/* USER CODE END 0 */

/**
  * @brief  The application entry point.
  * @retval int
  */
int main(void)
{

  /* MPU Configuration--------------------------------------------------------*/
  MPU_Config();

  /* Enable the CPU Cache */

  /* Enable I-Cache---------------------------------------------------------*/
  SCB_EnableICache();

  /* Enable D-Cache---------------------------------------------------------*/
  SCB_EnableDCache();

  /* MCU Configuration--------------------------------------------------------*/

  /* Reset of all peripherals, Initializes the Flash interface and the Systick. */
  HAL_Init();

  /* Configure the system clock */
  SystemClock_Config();

  /* Configure the peripherals common clocks */
  PeriphCommonClock_Config();

  /* Initialize all configured peripherals */
  MX_GPIO_Init();
  MX_ADC1_Init();
  MX_ADC2_Init();
  MX_LPTIM1_Init();
  MX_LPTIM5_Init();
  MX_USART1_UART_Init();
  MX_TIM2_Init();
  MX_TIM3_Init();
  MX_TIM5_Init();
  MX_TIM6_Init();
  /* USER CODE BEGIN 2 */
  logInit();

   {
      struct global_config *loadConfig;

      loadConfig=(struct global_config*)Flash_Storage_Read(sizeof(struct global_config),CONFIG_STRUCT_ID);
      if ((loadConfig) && (loadConfig->id==CONFIG_STRUCT_ID) && (loadConfig->ana0fac>0) && (loadConfig->ana1fac>0))
      {
         memcpy(&globalConfig,loadConfig,sizeof(struct global_config));
      }
   }
   if (HAL_GPIO_ReadPin(SET_DEFAULT_GPIO_Port,SET_DEFAULT_Pin)==GPIO_PIN_SET) // restore: keep the settings except the IP
   {
      globalConfig.ip.addr=STATIC_IP_ADDRESS_PORT1;
      globalConfig.gw.addr=STATIC_GW_ADDRESS_PORT1;
      globalConfig.nm.addr=STATIC_NM_ADDRESS_PORT1;
   }
   globalState.digiOut=globalConfig.digiInit;
   hw_gpio_set(globalState.digiOut);
   MX_LWIP_Init();
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

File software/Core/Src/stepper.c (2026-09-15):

#include "stepper.h"
#include "main.h"
#include "main_loop.h"
#include "hardware.h"

struct stepper_axes stepper={0,1,
                             {0,0,0,0,0,0,0},
                             {0,0,0,0,0,0,0},
                             {0,0,0,0,0,0,0},
                             0.0F,
                             NULL,0,0,
                             STOP,
                             HOMESTOP,
                             0
                            };


static uint32_t timerTickHz=9821428;


void stepper_timer_isr()
{
    if (stepper.state == STOP) {
        HAL_TIM_Base_Stop_IT(&htim6);
        return;
    }

    // STEP-Puls
    HAL_GPIO_TogglePin(stepper.stepPort,stepper.stepPin);
    globalState.digiOut^=stepper.stepBit;
    stepper.current_pos[stepper.currAxis]+=stepper.dir;

    int32_t remaining = stepper.target_pos[stepper.currAxis] - stepper.current_pos[stepper.currAxis];
    const float steps_to_stop=(stepper.v*stepper.v)/(2.0F*globalConfig.stepA[stepper.currAxis]);

    // ⚠️ Bremsbedingung hat Vorrang
    if (stepper.state!=DECEL)
    {
       switch (stepper.homing)
       {
          case HOME1IN:
          case HOME2IN:
             //reference switch was hit, so decelerate and stop
             if (HAL_GPIO_ReadPin(DIGI_IN_7_GPIO_Port,DIGI_IN_7_Pin)==GPIO_PIN_SET)
             {
                stepper.state=DECEL;
                stepper.target_pos[stepper.currAxis]=stepper.current_pos[stepper.currAxis]+(steps_to_stop*stepper.dir);
             }
             break;
          case HOME1OUT:
          case HOME2OUT:
             //reference switch was left, so decelerate and stop
             if (HAL_GPIO_ReadPin(DIGI_IN_7_GPIO_Port,DIGI_IN_7_Pin)==GPIO_PIN_RESET)
             {
                stepper.state=DECEL;
                stepper.target_pos[stepper.currAxis]=stepper.current_pos[stepper.currAxis]+(steps_to_stop*stepper.dir);
             }
             break;
          default:
             break;
       }
       if (abs(remaining)<=steps_to_stop)
       {
          stepper.state = DECEL;
       }
    }

    switch (stepper.state)
    {
       case ACCEL:
          stepper.v = sqrtf(stepper.v * stepper.v + 2.0f *globalConfig.stepA[stepper.currAxis]);
          if (stepper.v >=globalConfig.stepVmax[stepper.currAxis])
          {
             stepper.v =globalConfig.stepVmax[stepper.currAxis];
             stepper.state = CRUISE;
          }
          break;
       case CRUISE:
          // nichts tun
       default:
          break;
       case DECEL:
       {
          const float under_sqrt = stepper.v*stepper.v - 2.0f *globalConfig.stepA[stepper.currAxis];
          if (under_sqrt>0.0f)
          {
             stepper.v=sqrtf(under_sqrt);
          }
          if (stepper.v <= 0.0f || abs(remaining)==0)
          {
             stepper.v = 0.0f;
             stepper.state = STOP;
             return;
          }
          break;
       }
       case BRAKE:
       {
          const float under_sqrt = stepper.v*stepper.v - 2.0f *globalConfig.stepA[stepper.currAxis];
          if (under_sqrt>0.0f)
          {
             stepper.v=sqrtf(under_sqrt);
          }
          else
          {
             stepper.v=0.0f;
             stepper.target_pos[stepper.currAxis]=stepper.current_pos[stepper.currAxis];
             stepper.state=STOP;
             return;
          }
          break;
       }
    }
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

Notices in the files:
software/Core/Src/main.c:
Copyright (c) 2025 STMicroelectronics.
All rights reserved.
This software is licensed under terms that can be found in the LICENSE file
